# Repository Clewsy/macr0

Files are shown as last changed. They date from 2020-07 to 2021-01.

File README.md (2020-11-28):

# macr0

4-button HID compliant USB macro keypad.

A bunch of extra info can be found at [clews.pro][link_clews_macr0].

Goals for this project:
- [X] HID compliant USB peripheral using an ATmega32U4 microcontroller.
- [X] Keys will be mechanical Gateron switches - these are pin-compatible Cherry MX clones.
- [X] Keys will all be LED back-lit.
- [X] Back-light illumination will be adjustable.
- [X] Connectivity (and power) will be via a USC-C connector, configured for USB 2.0.

Proudly mentioned at [hackaday.com][link_web_hackaday_macr0]

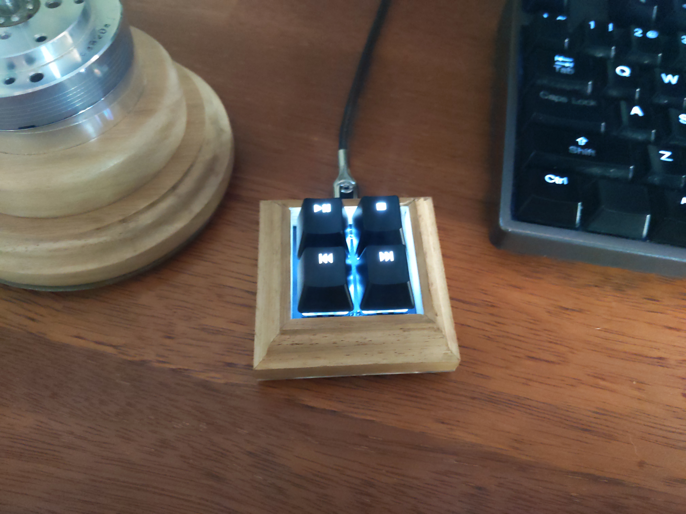
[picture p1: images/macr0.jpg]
The completed macr0 keypad.


[link_clews_macr0]:https://clews.pro/projects/macr0.php
[link_web_hackaday_macr0]:https://hackaday.com/2020/11/19/micro-macro-keyboard-is-mega-based/

[image_macr0]:images/macr0.jpg

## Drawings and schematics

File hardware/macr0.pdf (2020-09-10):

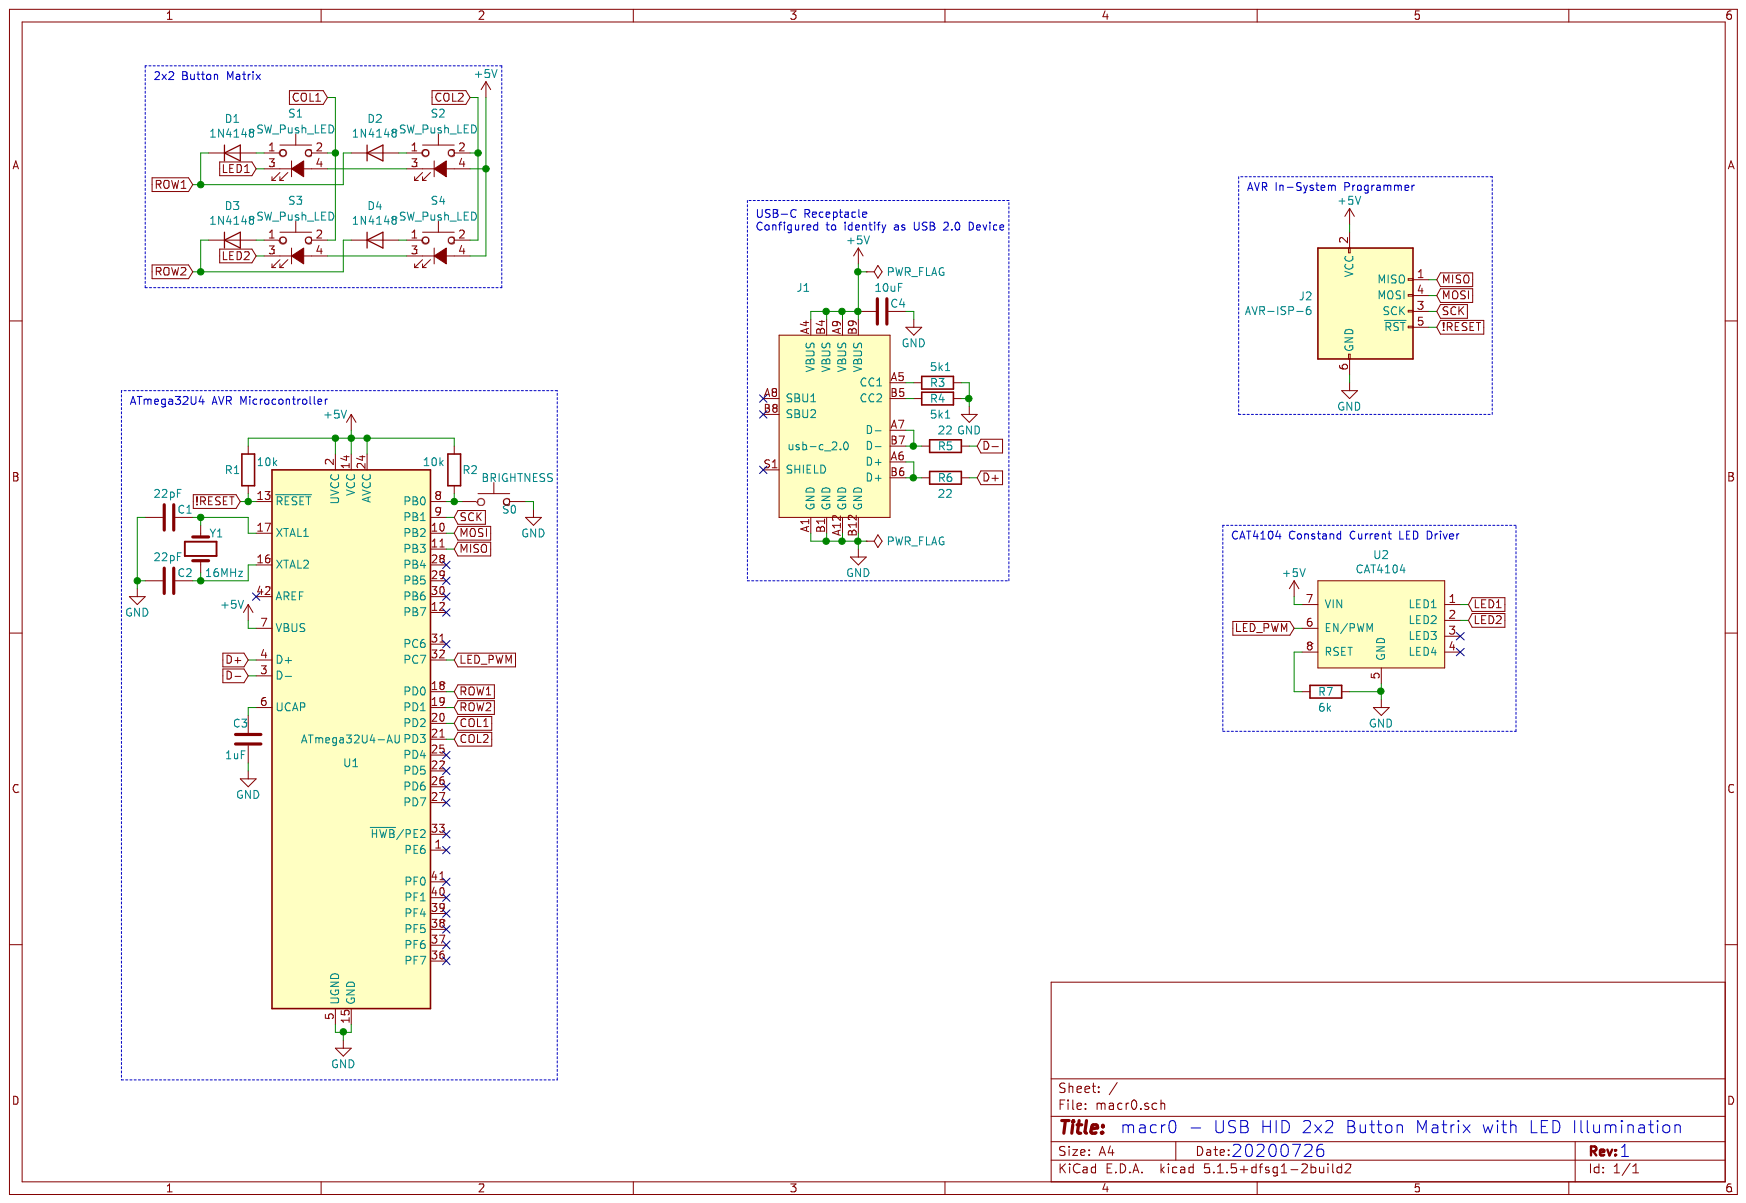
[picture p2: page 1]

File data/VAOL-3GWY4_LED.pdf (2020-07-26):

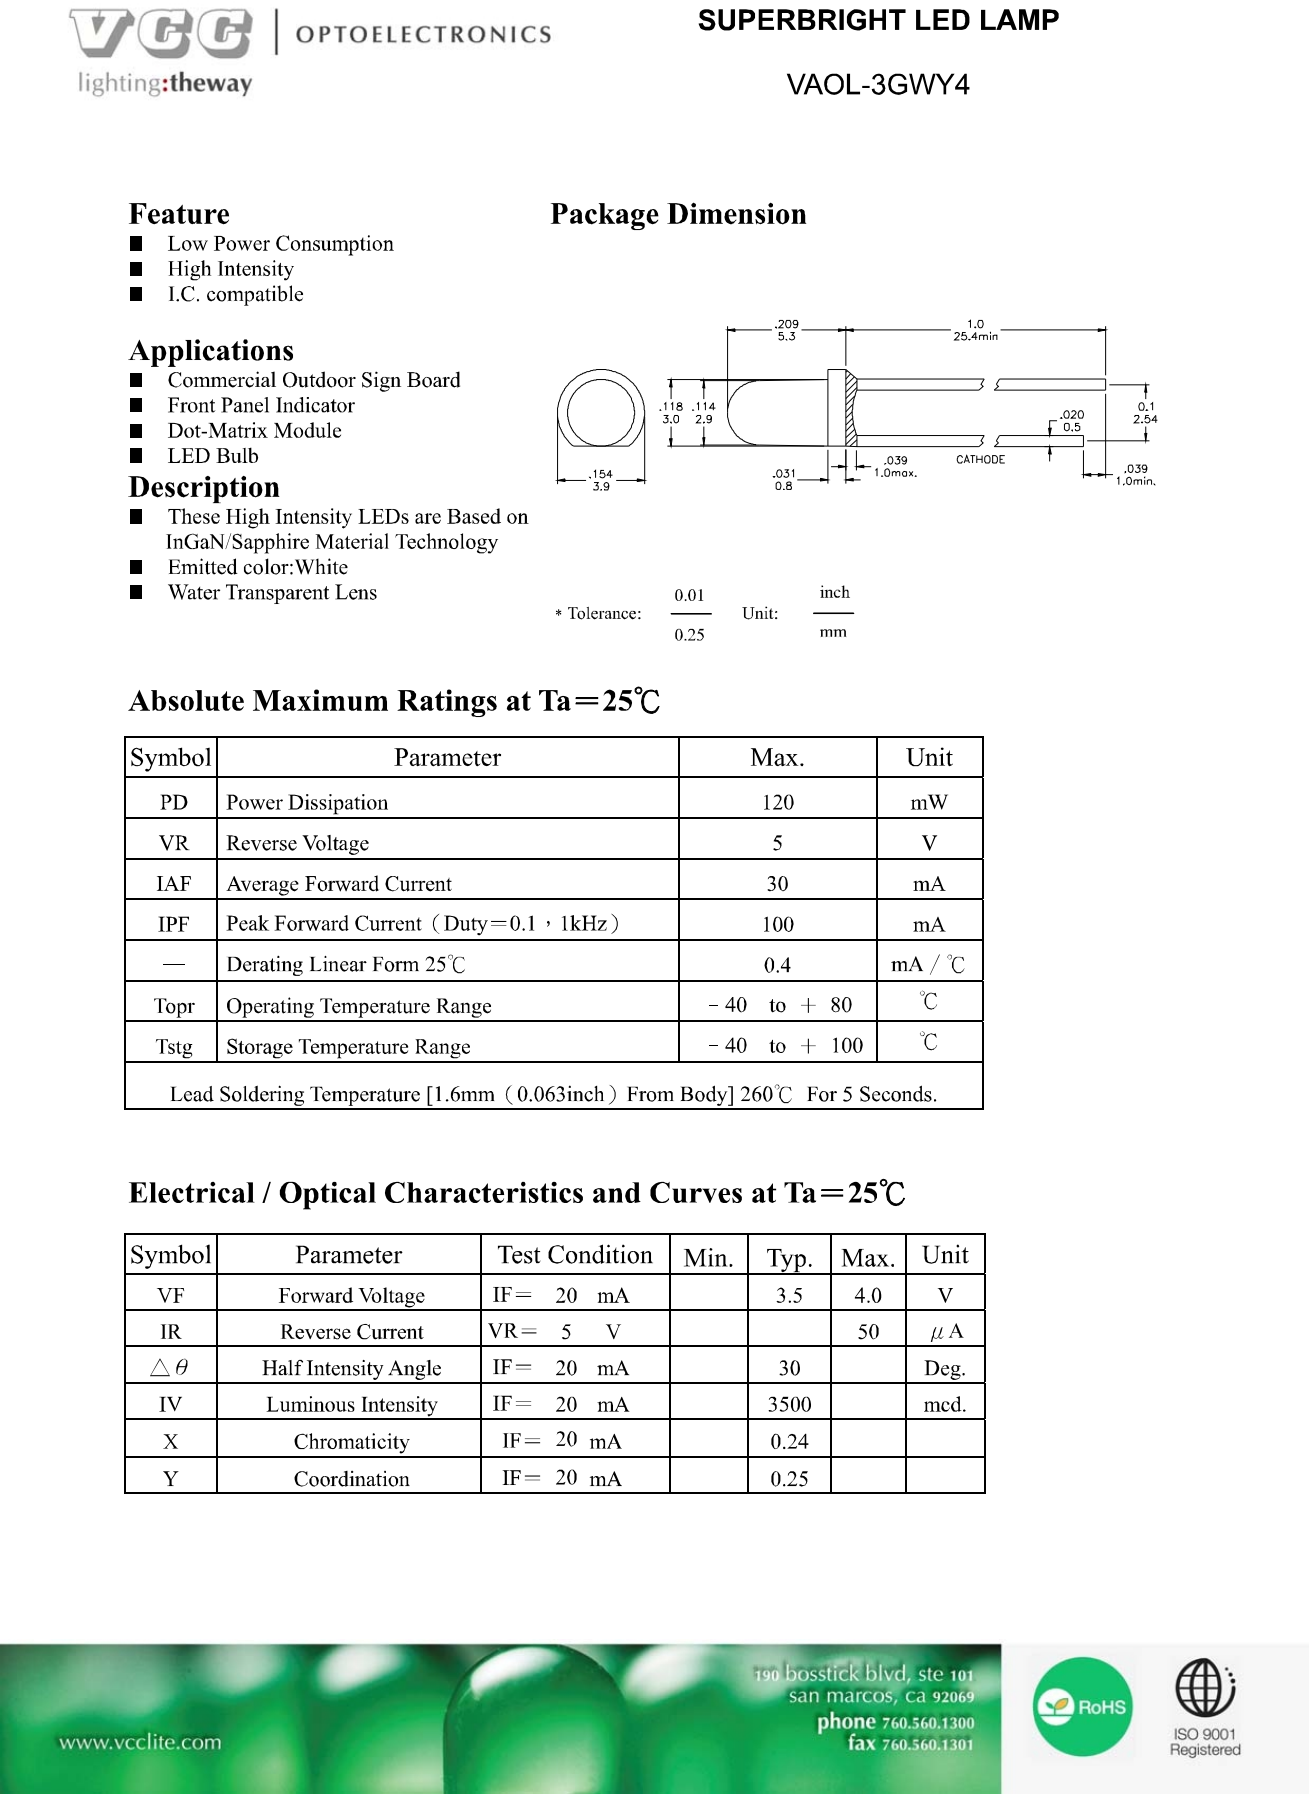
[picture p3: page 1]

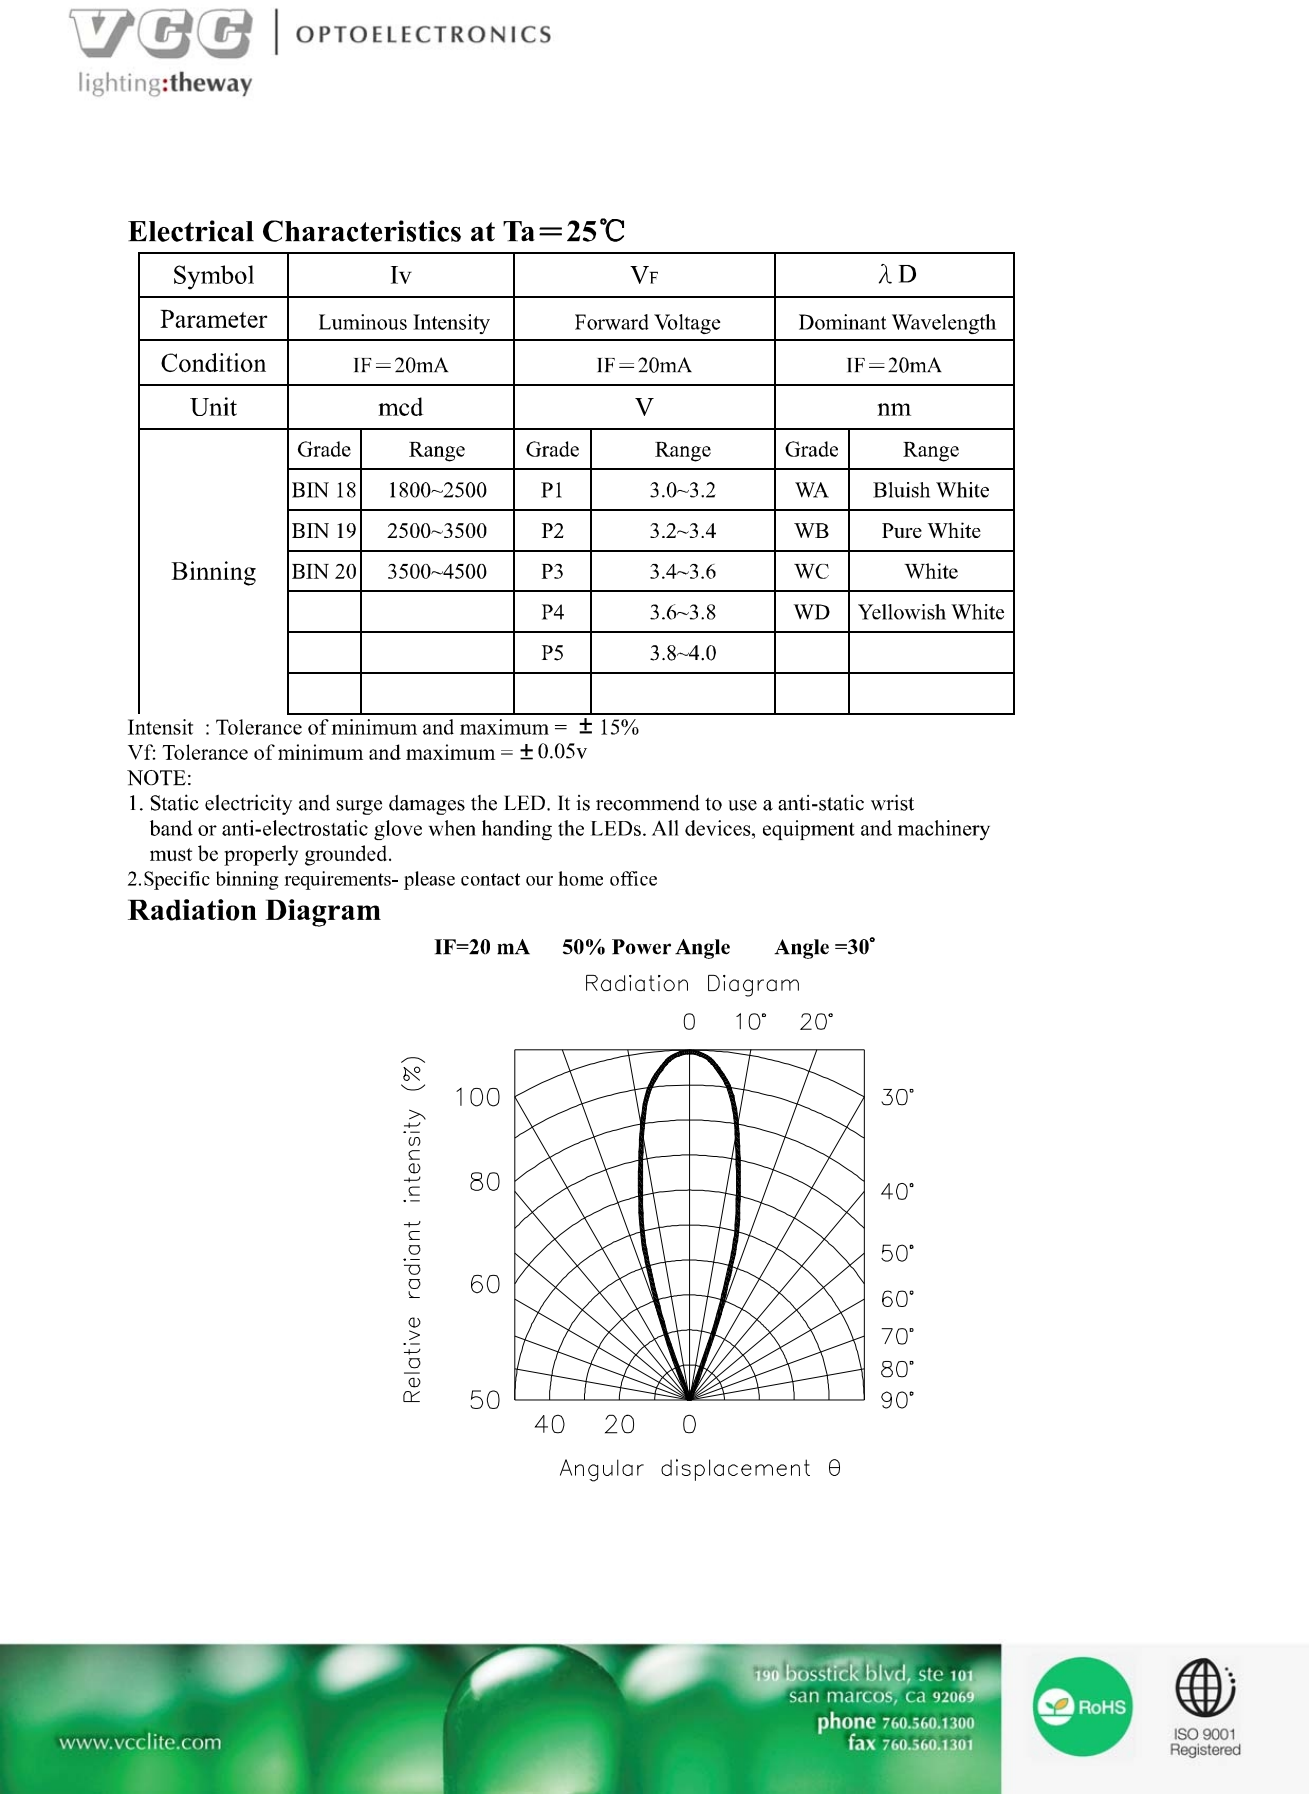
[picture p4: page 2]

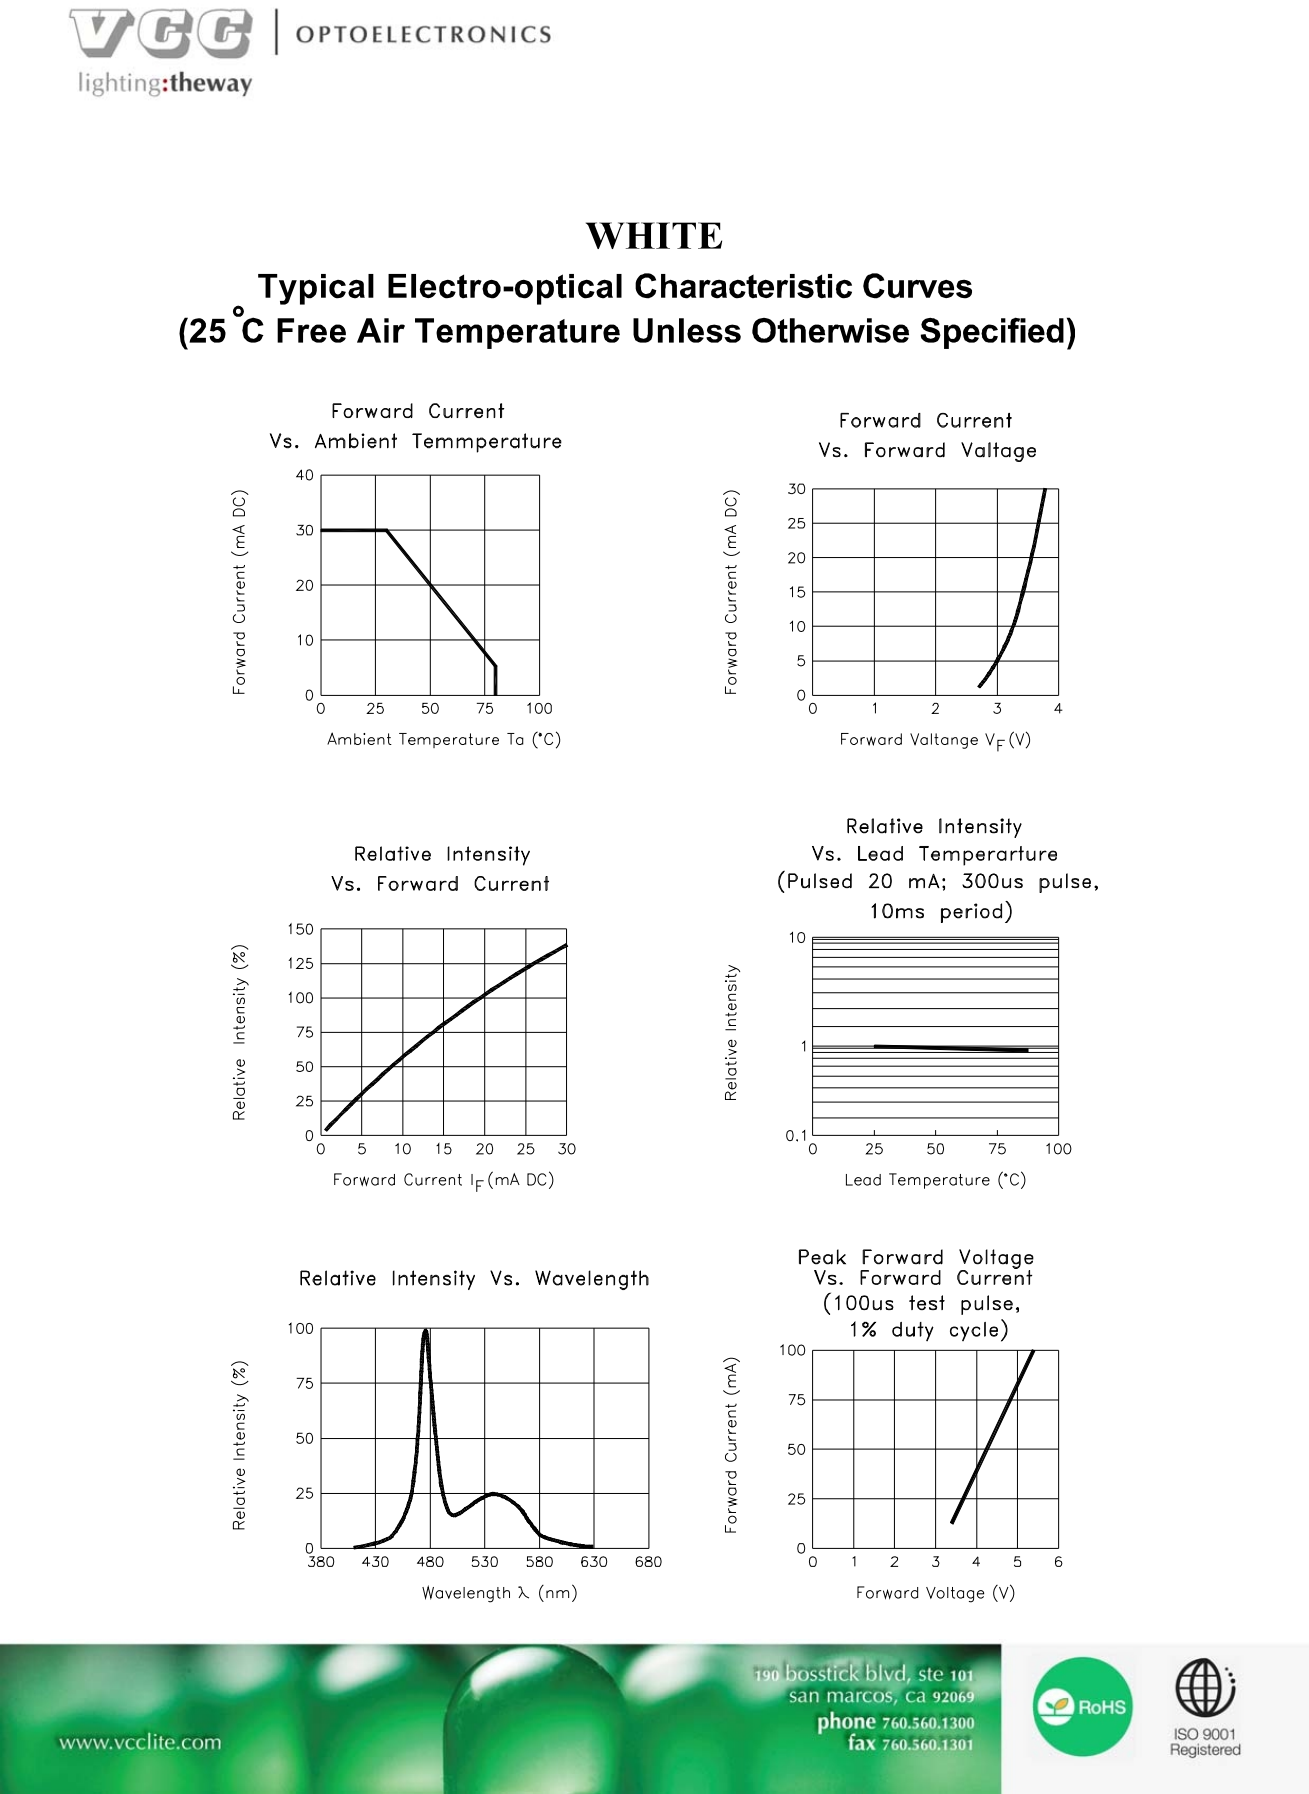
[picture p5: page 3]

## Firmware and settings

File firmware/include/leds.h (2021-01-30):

#include <avr/io.h>
#include <stdbool.h>	// Needed for using true/false booleans.
#include <util/delay.h>	// Needed for using _delay_ms() function.

// Definitions used for initiatilising and controling the led control button. 
#define BUTTON_PIN		PB0		// PB0 is also PCINT0 - Pin Change Interrupt Pin 0
#define BUTTON_PORT		PORTB		// Port register containing dimmer button pin (for setting DDR).
#define BUTTON_DDR		DDRB		// Data direction register for relevant port.
#define BUTTON_PINS		PINB		// Pins register ccontaining dimmer button pin (for readin pin state).
#define BUTTON_PCICR		PCICR		// Pin-change interrupt control register.
#define BUTTON_PCMSK		PCMSK0		// Pin-change mask.
#define BUTTON_PCIE		PCIE0		// Pin-change interrupt enable bit.
#define BUTTON_PCINT		PCINT0		// Pin-change interrupt bit.
#define BUTTON_PCI_VECTOR	PCINT0_vect	// Pin-change Interrupt sub-routine vector.
#define BUTTON_DEBOUNCE_MS	20		// Button de-bounce duration in milliseconds.

// Definitions used for initiatilising and controling the pwm output pin. 
#define PWM_PIN		PC7	// The pin to which the PWM signal will be connected.
#define PWM_PORT	PORTC	// The port register that includes the pwm pin.
#define PWM_DDR		DDRC	// Data direction register that corresponds to the relevant port.
#define PWM_SET		OCR4A	// Output compare register (writing 8-bits to here sets the pulse-width).
#define PWM_TCCRA	TCCR4A	// Timer/Counter Control Register
#define PWM_TCCRB	TCCR4B	// Timer/Counter Control Register
#define PWM_TCCRC	TCCR4C	// Timer/Counter Control Register
#define PWM_TCCRD	TCCR4D	// Timer/Counter Control Register
#define PWM_TCCRE	TCCR4E	// Timer/Counter Control Register
#define PWM_COM0	COM4A0	// Compare Output Mode Bit 0
#define PWM_COM1	COM4A1	// Compare Output Mode Bit 1
#define PWM_AE		PWM4A	// PWM on comparator A Enable
#define PWM_WGM0	WGM40	// Waveform Generation Mode Bit 0
#define PWM_WGM1	WGM41	// Waveform Generation Mode Bit 1
#define PWM_CS0		CS40	// Clock Select Bit 0
#define PWM_CS1		CS41	// Clock Select Bit 1
#define PWM_CS2		CS42	// Clock Select Bit 2
#define PWM_CS3		CS43	// Clock Select Bit 3

// Definitions used for initiatilising and controling the pulse timer. 
#define PULSER_TCCRA		TCCR1A			// Timer/Counter Control Register A
#define PULSER_TCCRB		TCCR1B			// Timer/Counter Control Register B
#define PULSER_WGM3		WGM13			// Timer/Counter Waveform Generation Mode Bit 3
#define PULSER_WGM2		WGM12			// Timer/Counter Waveform Generation Mode Bit 2
#define PULSER_WGM1		WGM11			// Timer/Counter Waveform Generation Mode Bit 1
#define PULSER_WGM0		WGM10			// Timer/Counter Waveform Generation Mode Bit 0
#define PULSER_CS2		CS12			// Timer/Counter Clock Select Bit 2
#define PULSER_CS1		CS11			// Timer/Counter Clock Select Bit 1
#define PULSER_CS0		CS10			// Timer/Counter Clock Select Bit 0
#define PULSER_SET_REG		OCR1A			// Timer/Counter Output Compare Register
#define PULSER_TIMSK		TIMSK1			// Timer/Counter Timer Interrupt Mask Register
#define PULSER_IE		OCIE1A			// Timer Output Compare Interrupt Enable Bit.
#define PULSER_INT_VECTOR	TIMER1_COMPA_vect	// Interrupt subroutine name.

// Mode definitions.
#define NUM_MODES	(sizeof(modes) / sizeof modes[0])	// Macro for returning the total number of modes.
#define START_MODE	1					// The led mode at start-up.

// Declarations:
struct mode
{
	uint8_t initial_brightness;
	uint16_t pulse_speed;
};
void leds_init(void);
void leds_pwm_set(uint8_t duty);
uint8_t leds_pwm_get(void);
void leds_pulse_enable(bool enable);
void leds_pulse_speed_set(uint16_t speed);
void leds_set_mode(uint8_t mode);
void leds_handle_pulser_interrupt(void);
void leds_change_mode(void);
void leds_button_enable(bool enable);
bool leds_button_state(void);

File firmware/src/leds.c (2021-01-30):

#include "leds.h"

// Each "mode" is defined by a uint8_t for brightness and a uint16_t for pulse speed.
// initial_brightness:	The PWM value to send to the LEDs before setting the pulse speed.  Note, the LEDs are active low, so full
//			brightness requires a value of 0xFF.  Range is 0 to 255 (0x00 to 0xFF).
// pulse_speed:		When the pulse timer counter reaches this value, an interrupt is triggered that changes the PWM value.
//			Set to zero for no pulse effect.  Range is 0 to 65535 (0x0000 to 0xFFFF).
const struct mode modes[] = 
{
	{ .initial_brightness = 255, 	.pulse_speed = 0},	// Mode 00 - Off.
	{ .initial_brightness = 254, 	.pulse_speed = 0},	// Mode 01
	{ .initial_brightness = 253, 	.pulse_speed = 0},	// Mode 02
	{ .initial_brightness = 251, 	.pulse_speed = 0},	// Mode 03
	{ .initial_brightness = 247, 	.pulse_speed = 0},	// Mode 04
	{ .initial_brightness = 239, 	.pulse_speed = 0},	// Mode 05
	{ .initial_brightness = 223, 	.pulse_speed = 0},	// Mode 06
	{ .initial_brightness = 191, 	.pulse_speed = 0},	// Mode 07
	{ .initial_brightness = 127, 	.pulse_speed = 0},	// Mode 08
	{ .initial_brightness = 0, 	.pulse_speed = 0},	// Mode 09 - Max brightness.
	{ .initial_brightness = 0, 	.pulse_speed = 2000},	// Mode 10 - Fast pulse.
	{ .initial_brightness = 0, 	.pulse_speed = 8000},	// Mode 11 - Medium pulse.
	{ .initial_brightness = 0, 	.pulse_speed = 32000},	// Mode 12 - Slow pulse.
};

// Initialise the AVR registers for controlling the LEDs.
// The hardware configuration has the pwm pin connected to a PNP transistor that controls all LEDs on the anode side.
void leds_init(void)
{
	////////Initialise the button interrupt.
	BUTTON_DDR &= ~(1 << BUTTON_PIN);	// Set button pin as input.
	BUTTON_PORT |= (1 << BUTTON_PIN);	// Enable internal pull-ups.
	BUTTON_PCMSK |= (1 << BUTTON_PCINT);	// Enable pin-change interrupt for selected pin.

	////////Initialise the pwm timer.
	PWM_DDR |= (1 << PWM_PIN);	// Set the PWM pin as an output.
	// WGM[1:0] set to 00 : Fast PWM mode.
	// COM[1:0] set to 10 : Clear on compare match, set at bottom (TCNT4 = 0x00), OC4A pin connected.
	// PWM_AE set to enable PWM on comparator A.
	// CS[3:0] set to 0111 : clk = CK/64 = 250,000Hz.  PWM_freq = clk/256 = 964.5625Hz
	PWM_TCCRA |= ((1 << PWM_COM1) | (1 << PWM_AE));
	PWM_TCCRB |= ((0 << PWM_CS3) | (1 << PWM_CS2) | (1 << PWM_CS1) | (1 << PWM_CS0));
	PWM_DDR |= (1 << PWM_PIN);	// Set as an output the pin to which the LEDs transistor is connected.

	////////Initialise the pulse effect timer.
	// WGM[2:0] set to 0100 : CTC mode, counts from 0 to value of output compare register.
	// COM[1:0] set to 00 : Normal pin modes - not connected to timer.
	// CS[2:0] set to 010 : clk/8 (from prescaler).
	PULSER_TCCRB |= ((1 << PULSER_WGM2) | (1 << PULSER_CS1));

	// Set the default (start-up) led mode.
	leds_set_mode(START_MODE);

	// Enable the led mode button.
	leds_button_enable(true);
}

// Set the current duty cycle (0 to 255).
void leds_pwm_set(uint8_t duty)
{
	PWM_SET = duty;
}

// Get the current duty cycle (0 to 255).
uint8_t leds_pwm_get(void)
{
	return(PWM_SET);
}

// Enable or disable the pulse effect.
void leds_pulse_enable(bool enable)
{
	if(enable)	PULSER_TIMSK |= (1 << PULSER_IE);	// Enable the output compare interrupt.
	else		PULSER_TIMSK &= ~(1 << PULSER_IE);	// Disable the output compare interrupt.
}

// Set the counter value that will trigger the interrupt.  Also disable the interrupt if the selected speed is zero.
void leds_pulse_speed_set(uint16_t speed)
{
	PULSER_SET_REG = speed;

	if(speed)	leds_pulse_enable(true);
	else		leds_pulse_enable(false);	// Enable pulse only if speed is not zero.
}

// Using the look-up table ("modes"), set the desired brightness (pwm value) and pulse speed.
void leds_set_mode(uint8_t led_mode)
{
	leds_pwm_set(modes[led_mode].initial_brightness);
	leds_pulse_speed_set(modes[led_mode].pulse_speed);
}

// Update the pwm value when the pulse effect interrupt is triggered.
void leds_handle_pulser_interrupt(void)
{
	static int8_t led_pulse_direction = 1;	// Static so it is initiaised once but retained for future invocations.
	uint8_t current_pwm = leds_pwm_get();	// Check the current pwm value.

	if	(current_pwm == 255)	led_pulse_direction = -1;	// Start decreasing.
	else if	(current_pwm == 0)	led_pulse_direction = 1;	// Start increasing.

	leds_pwm_set(current_pwm + led_pulse_direction);		// Update the led brightness.
}

// Cycle through the various led modes.
void leds_change_mode(void)
{
	static uint8_t led_mode = START_MODE;	// Static so it is initiaised once but retained for future invocations.

	if(led_mode == (NUM_MODES - 1))	led_mode = 0;	// Cycle back to the first mode if last mode reached.
	else				led_mode++;	// Else just increment to the next mode.

	leds_set_mode(led_mode);
}

// Enable pr disable the mode button.
void leds_button_enable(bool enable)
{
	if(enable)	BUTTON_PCICR |= (1 << BUTTON_PCIE);	// Enable the button pin-change interrupt.
	else		BUTTON_PCICR &= ~(1 << BUTTON_PCIE);	// Disable the button pin-change interrupt.
}

// Check the state of the pin.  Returns true if pressed.
bool leds_button_state(void)
{
	if(~BUTTON_PINS & (1 << BUTTON_PIN))	return(true);
	else					return(false);
}

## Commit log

2020-07-20 Initialise project repo. Working on schematic.
    [macr0.kicad_pcb, macr0.sch]
2020-07-26 Finished schametic. Working on PCB layout.
    [macr0.kicad_pcb, macr0.sch]
2020-07-26 First prototype pcb for fab.
    [macr0-B_Cu.gbr, macr0-B_Mask.gbr, macr0-B_SilkS.gbr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]
2020-07-26 Added logo to pcb. Created readme.
    [macr0-B_Cu.gbr, macr0-B_Mask.gbr, macr0-B_SilkS.gbr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]
2020-08-03 USB receptacle was a deprecated part but I found a better one intended for USB 2.0 devices.
    [macr0-B_Cu.gbr, macr0-B_Mask.gbr, macr0-B_SilkS.gbr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]
2020-08-17 Renamed hardware directory and fixed readme typo.
    [macr0-B_Cu.gbr, macr0-B_Mask.gbr, macr0-B_SilkS.gbr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]
2020-08-26 Silkscreen correction and improvements.
    [macr0.kicad_pcb, macr0.sch]
2020-08-28 Messy, but the LED dimmer adjustment is working.
2020-08-28 Messy but proof-of-concept key scan working. Buttons print a, b, c or d.
2020-08-30 I'm so bad at this, I can't even spell my name correctly.
    [macr0.kicad_pcb]
2020-09-10 Schematic pdf.
2020-09-11 Working on hardware rev2.
    [macr0.kicad_pcb, macr0.sch]
2020-09-17 Rev2 pcb arrived and assembled. Code updated to reflect changes.
2020-10-17 Improved LED controller. Added pulse effect.
2020-10-18 Improved efficiency and readability of led control functions.
2020-10-18 Changed initial led mode.
2020-10-23 Improvements - configuration of keys/macros requires only edits to keymap.c, blank macro no longer needed in macro array.
    [leds.c]
2021-01-30 Fixed a bug with occasional skipping over led modes.
    [leds.c, leds.h]
